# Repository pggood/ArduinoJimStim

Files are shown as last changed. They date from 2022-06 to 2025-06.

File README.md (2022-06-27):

# ArduinoJimStim an Arduino implementation of the JimStim used for megasquirt

A pattern based ignition emulator with 44 common ignition and cam patterns . 

The patterns are in 

wheels_default.h 

Each pattern is a sequence where the first digit is the ignition and cam pulse and the second is the number of degrees it applies for .

The sequence is terminated with 0xff,0, where it loops Back to the beginning.

As it is writing directly to PORTB you could potentially have up to 6 outputs in the pattern.

- 00 is all off
- 01 is ignition on cam off
- 02 is cam on ignition off
- 03 is both cam and ignition on

These patterns can either be for 360 degrees or 720 degrees.

If you are constructing a pattern be careful to add up all the degrees in the second field and make sure it adds up to either 360 or 720

This can be done in a spreadsheet first.

The repository holds the Ardunio source code as well as the Kicad PCB Schematic and gerber files that can be made by people like pcbway, jlcpcb or whoever you preferred PCB maker is. The design is through hole so can be put together by a hobbyist with basic soldering skills.

This is completely open source so do with it as you wish however it is provided on the basis that you use it with your best skill and knowledge and may contain bugs

Wheel Number|DIP Switch  |Wheel Mode                       |Type              |Cam Signal
------------|------------|---------------------------------|------------------|----------  
0           |000000      |Distributor/EDIS|Distributor/EDIS|                  |
1           |000001      |36-1                             |36-1              |X
2           |000010      |60-2                             |60-2              |X
3           |000011      |4-1                              |4-1               |X
4           |000100      |24/2 (Nippondenso)               |24/2 (Nippondenso)|X
5           |000101      |NGC 4 cyl. 36-1+1                |NGC 4 cyl. 36-1+1 |X
6|000110|36-2-2-2|36-2-2-2|X
7|000111|6-1|6-1|X
8|001000|Neon/420A|Neon/420A|X
9|001001|LS1|24+rising/falling (LS1)|X
10|001010|12-1|12-1|X
11|001011|Subaru 6/7|Subaru 6/7|X
12|001100|Trigger return|Trigger return dizzy|
13|001101|Oddfire VR|Oddfire dizzy|
14|001110|Mitsubishi 6G72|Mitsubishi 6G72|X
16|010000|CAS 4/1|4/1 CAS|X
17|010001|4G63|4G63 (Miata)|X
18|010010|Renix 44-2-2|Renix 44-2-2|
19|010011|Twin trigger even|Twin trigger even|X
20|010100|Twin trigger odd|Twin trigger odd|X
21|010101|Suzuki Swift|Suzuki Swift|
22|010110|Suzuki Vitara 2.0|Suzuki Vitara 2.0|
23|010111|Daihatsu 3 cyl|Daihatsu 3 cyl|
24|011000|Daihatsu 4 cyl|Daihatsu 4 cyl|
25|011001|Miata 99-00|Miata 99-00|X
26|011010|Rover 36-1-1|Rover 36-1-1|X
27|011011|Rover 36-1-1-1-1|Rover 36-1-1-1-1|X
28|011100|Rover 36-2-2|Rover 36-2-2|X
29|011101|Honda RC51|Honda RC51|X
30|011110|Chrysler 2.2/2.5|Chrysler 2.2/2.5|X
31|011111|Do not select this|Do not select this|
32|100000|GM 7x native|GM 7x native|
33|100001|32-2 Harley|32-2 Harley|
34|100010|6/1|6/1|X
35|100011|8/1|8/1|X
36|100100|10/1|10/1|X
37|100101|Honda VTR1000 12-3|Honda VTR1000 12-3|
38|100110|IAW Weber-Marelli|IAW Weber-Marelli|X
39|100111|Fiat 1.8 16V|Fiat 1.8 16V|X
40|101000|Mitsubishi 360 tooth CAS (6 cyl)|Mitsubishi 360 tooth CAS (6 cyl)|X
41|101001|Mitsubishi 360 tooth CAS (8 cyl)|Mitsubishi 360 tooth CAS (8 cyl)|X
42|101010|4.0 Jeep 2000|4.0 Jeep 2000|X
43|101011|3.7 Jeep 2002|3.7 Jeep 2002|X
44|101100|NGC 6 cyl. 36-1+1|NGC 6 cyl. 36-1+1|X
45|101101|NGC 8 cyl. 36-1+1|NGC 8 cyl. 36-1+1|X

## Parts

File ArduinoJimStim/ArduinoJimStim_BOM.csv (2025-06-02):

Id | Designator | Package | Quantity | Designation | Supplier and ref
1 | RN1 | R_Array_SIP9 | 1 | R_Network08_US
2 | D2,D8,D4,D5,D1,D6,D11,D10,D9,D7,D12,D3 | LED_D3.0mm_Clear | 12 | LED
3 | J10 | BarrelJack_Horizontal | 1 | Barrel_Jack
4 | R10,R15,R17,R12,R14,R13,R16,R4,R11,R6,R3,R8 | R_Axial_DIN0204_L3.6mm_D1.6mm_P7.62mm_Horizontal | 12 | 330
5 | J4 | PinHeader_1x01_P2.54mm_Vertical | 1 | 2ND Trigger
6 | C1 | C_Radial_D8.0mm_H11.5mm_P3.50mm | 1 | 100n
7 | J3 | PinHeader_1x02_P2.54mm_Vertical | 1 | O2
8 | J8,J7 | PinHeader_1x01_P2.54mm_Vertical | 2 | 12v
9 | D13 | D_A-405_P12.70mm_Horizontal | 1 | D
10 | J5 | DSUB-37_Female_Horizontal_P2.77x2.84mm_EdgePinOffset4.94mm_Housed_MountingHolesOffset7.48mm | 1 | DB37_Male
11 | MAT1,CLT1,RPM1,O2,TPS1 | Potentiometer_Vishay_148-149_Single_Horizontal | 5 | 10K
12 | Q2,Q1 | TO-92_Inline | 2 | 2N3904
13 | R5,R1,R2,R7,R9 | R_Axial_DIN0204_L3.6mm_D1.6mm_P7.62mm_Horizontal | 5 | 1K
14 | J1 | PinHeader_1x03_P2.54mm_Vertical | 1 | TACH
15 | J2 | PinHeader_2x03_P2.54mm_Vertical | 1 | Conn_02x03_Odd_Even
16 | SW1 | MTS-101_SPST | 1 | SW_SPST
17 | A1 | Arduino_Nano | 1 | Arduino_Nano_v3.x
18 | J9 | PinHeader_1x10_P2.54mm_Vertical | 1 | Conn_01x10_Female
19 | SW2 | SW_DIP_SPSTx06_Slide_9.78x17.42mm_W7.62mm_P2.54mm | 1 | SW_DIP_x06
20 | J6 | PinHeader_1x19_P2.54mm_Vertical | 1 | Conn_01x19_Male

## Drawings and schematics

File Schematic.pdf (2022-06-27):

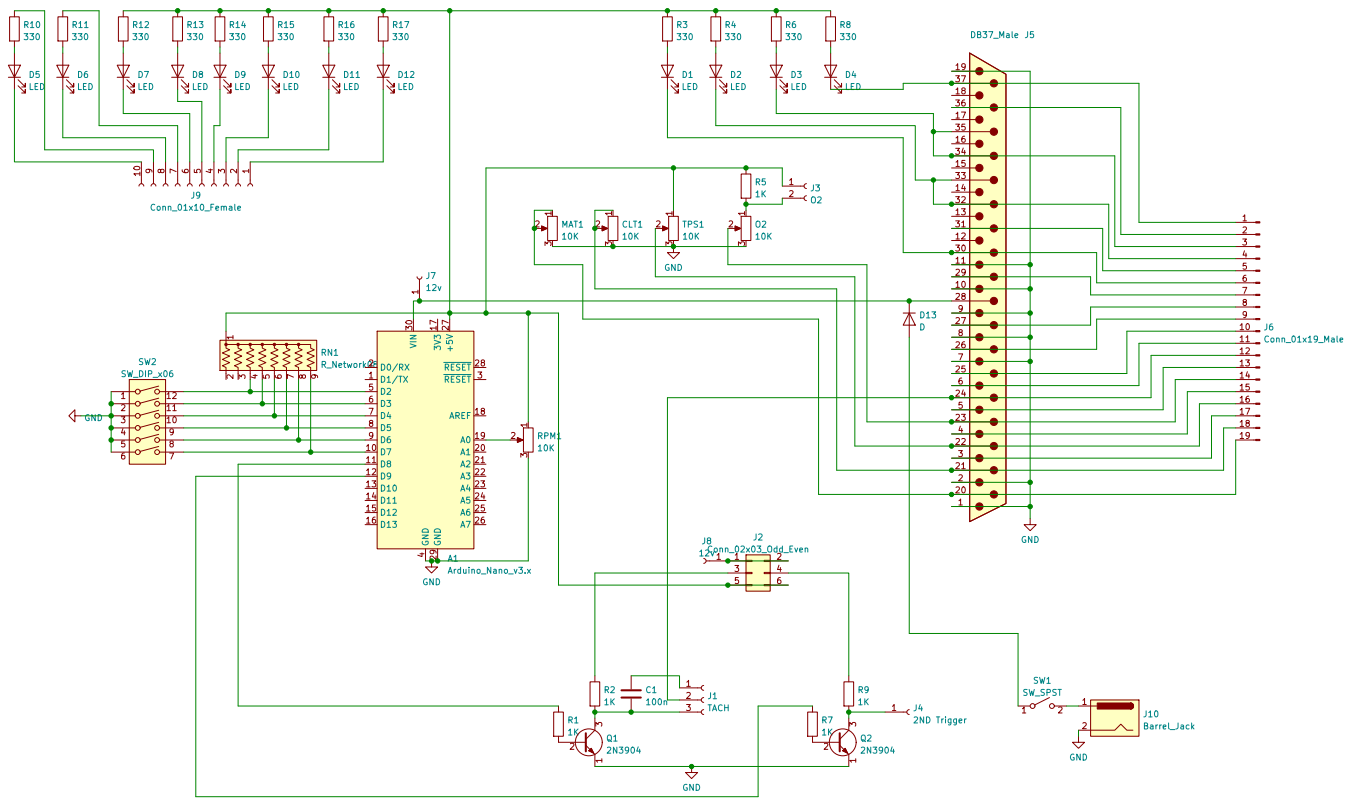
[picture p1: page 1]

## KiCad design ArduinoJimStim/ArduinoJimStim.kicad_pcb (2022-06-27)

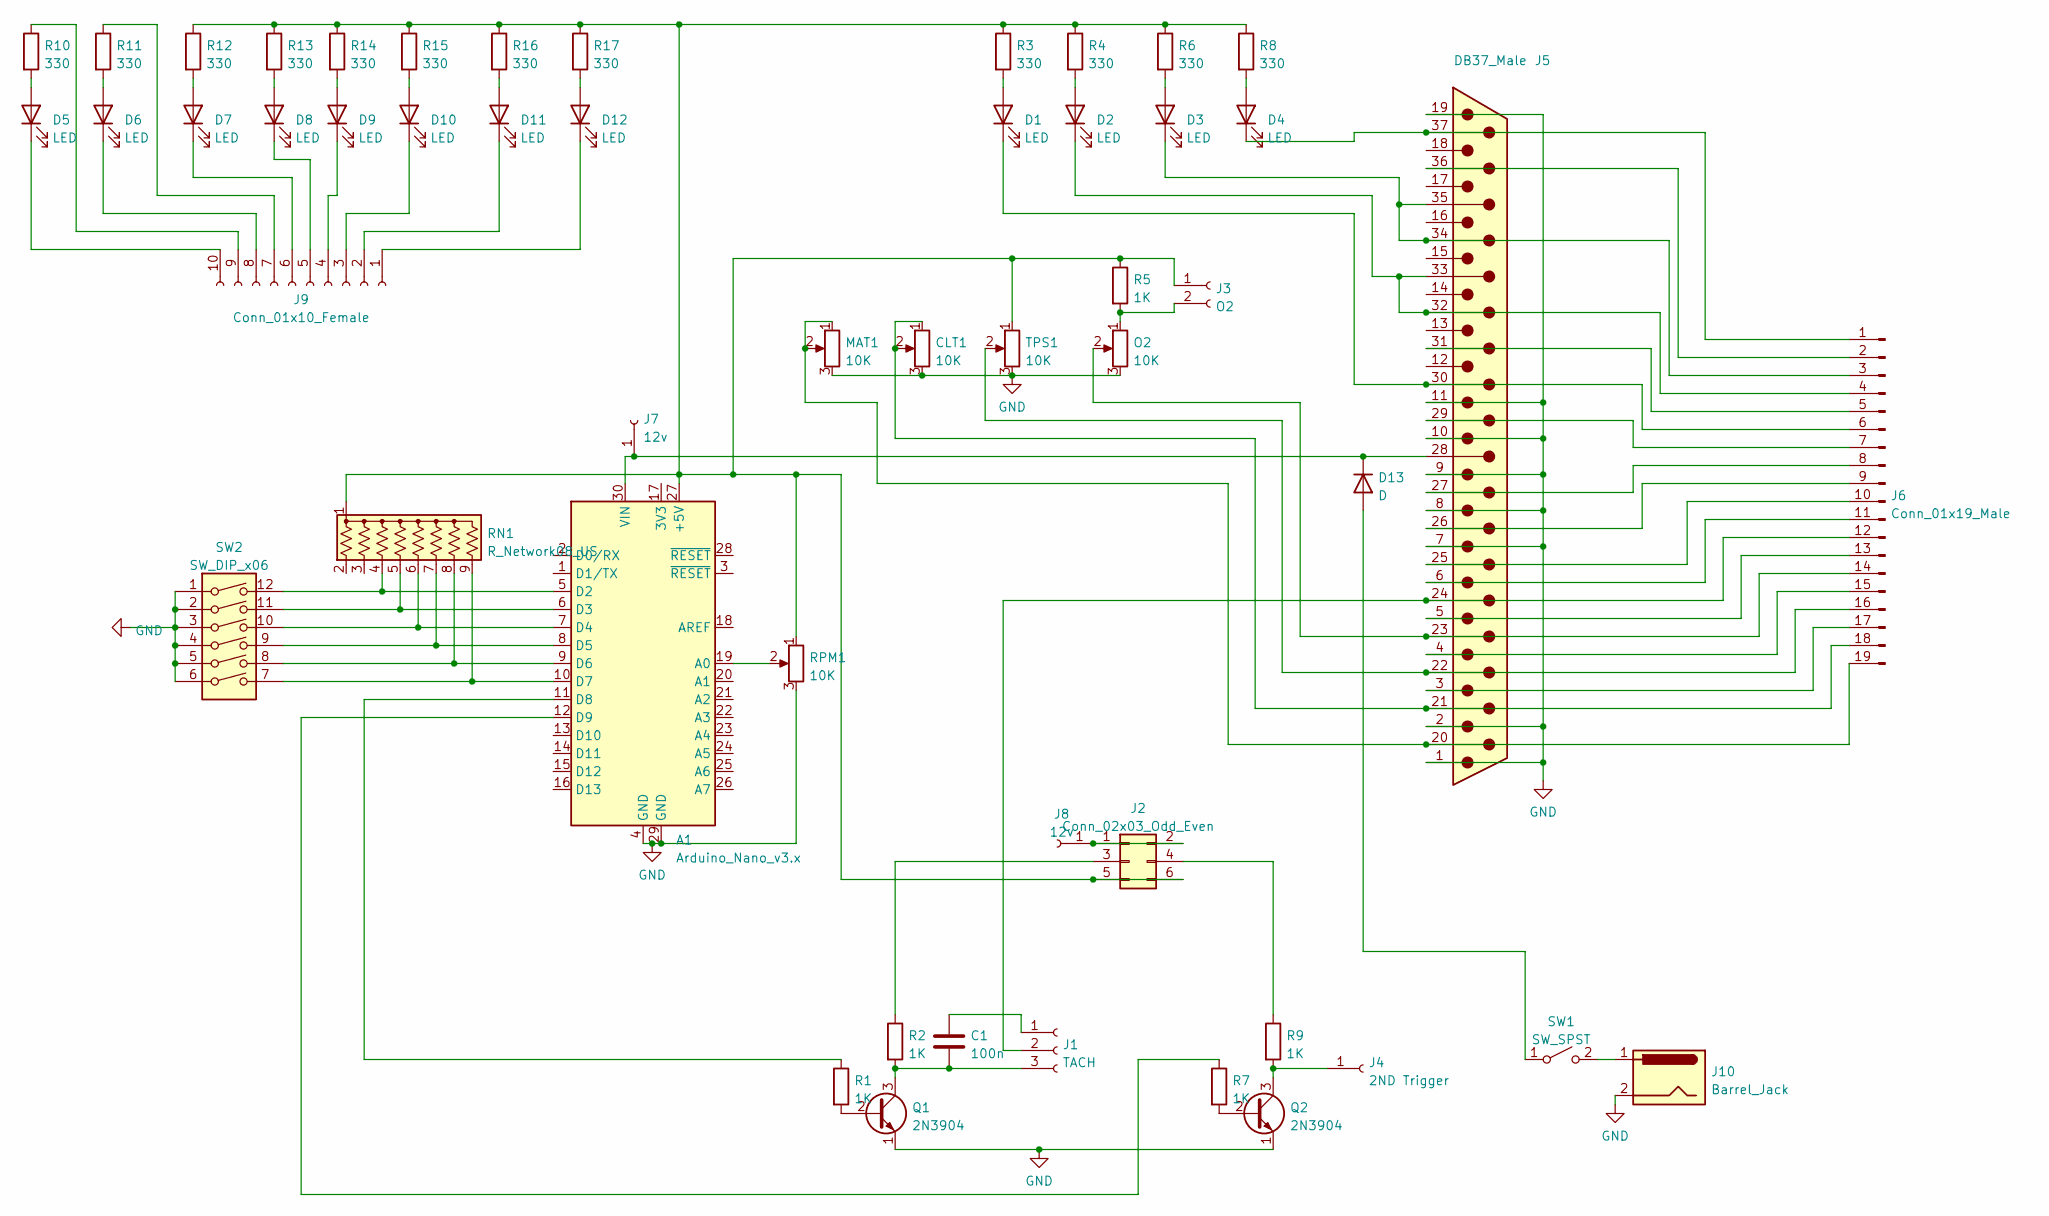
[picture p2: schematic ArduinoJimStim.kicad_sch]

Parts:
A1: Arduino_Nano_v3.x; Arduino_Nano
C1: 100n; C_Radial_D8.0mm_H11.5mm_P3.50mm
CLT1: 10K; Potentiometer_Vishay_148-149_Single_Horizontal
D1, D2, D3, D4, D5, D6, D7, D8, D9, D10, D11, D12: LED; LED_D3.0mm_Clear
D13: D; D_A-405_P12.70mm_Horizontal
J1: TACH; PinHeader_1x03_P2.54mm_Vertical
J2: Conn_02x03_Odd_Even; PinHeader_2x03_P2.54mm_Vertical
J3: O2; PinHeader_1x02_P2.54mm_Vertical
J4: 2ND Trigger; PinHeader_1x01_P2.54mm_Vertical
J5: DB37_Male; DSUB-37_Female_Horizontal_P2.77x2.84mm_EdgePinOffset4.94mm_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
J6: Conn_01x19_Male; PinHeader_1x19_P2.54mm_Vertical
J7, J8: 12v; PinHeader_1x01_P2.54mm_Vertical
J9: Conn_01x10_Female; PinHeader_1x10_P2.54mm_Vertical
J10: Barrel_Jack; BarrelJack_Horizontal
MAT1: 10K; Potentiometer_Vishay_148-149_Single_Horizontal
O2: 10K; Potentiometer_Vishay_148-149_Single_Horizontal
Q1, Q2: 2N3904; TO-92_Inline
R1, R2, R5, R7, R9: 1K; R_Axial_DIN0204_L3.6mm_D1.6mm_P7.62mm_Horizontal
R3, R4, R6, R8, R10, R11, R12, R13, R14, R15, R16, R17: 330; R_Axial_DIN0204_L3.6mm_D1.6mm_P7.62mm_Horizontal
RN1: R_Network08_US; R_Array_SIP9
RPM1: 10K; Potentiometer_Vishay_148-149_Single_Horizontal
SW1: SW_SPST; MTS-101_SPST
SW2: SW_DIP_x06; SW_DIP_SPSTx06_Slide_9.78x17.42mm_W7.62mm_P2.54mm
TPS1: 10K; Potentiometer_Vishay_148-149_Single_Horizontal

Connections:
GND: A1.4 (GND), A1.29 (GND), CLT1.3, J5.1, J5.2, J5.7, J5.8, J5.9, J5.10, J5.11, J5.19, J10.2, MAT1.3, O2.3, Q1.1 (E), Q2.1 (E), RPM1.3, SW2.1, SW2.2, SW2.3, SW2.4, SW2.5, SW2.6, TPS1.3
unnamed: A1.5 (D2), RN1.4 (R3), SW2.12
unnamed: A1.6 (D3), RN1.5 (R4), SW2.11
unnamed: A1.7 (D4), RN1.6 (R5), SW2.10
unnamed: A1.8 (D5), RN1.7 (R6), SW2.9
unnamed: A1.9 (D6), RN1.8 (R7), SW2.8
unnamed: A1.10 (D7), RN1.9 (R8), SW2.7
unnamed: A1.11 (D8), R1.1
unnamed: A1.12 (D9), R7.1
unnamed: A1.19 (A0), RPM1.2
unnamed: A1.27 (+5V), J2.5, J2.6, J3.1, R3.1, R4.1, R5.1, R6.1, R8.1, R12.1, R13.1, R14.1, R15.1, R16.1, R17.1, RN1.1 (common), RPM1.1, TPS1.1
unnamed: A1.30 (VIN), D13.1 (K), J5.28, J7.1
unnamed: C1.1, J1.1
unnamed: C1.2, J1.3, Q1.3 (C), R2.2
unnamed: CLT1.1, CLT1.2, J5.21, J6.18
unnamed: D1.1 (K), J5.30, J6.6
unnamed: D1.2 (A), R3.2
unnamed: D2.1 (K), J5.32, J5.33, J6.4
unnamed: D2.2 (A), R4.2
unnamed: D3.1 (K), J5.34, J5.35, J6.3
unnamed: D3.2 (A), R6.2
unnamed: D4.1 (K), J5.37, J6.1
unnamed: D4.2 (A), R8.2
unnamed: D5.1 (K), J9.10
unnamed: D5.2 (A), R10.2
unnamed: D6.1 (K), J9.8
unnamed: D6.2 (A), R11.2
unnamed: D7.1 (K), J9.6
unnamed: D7.2 (A), R12.2
unnamed: D8.1 (K), J9.5
unnamed: D8.2 (A), R13.2
unnamed: D9.1 (K), J9.4
unnamed: D9.2 (A), R14.2
unnamed: D10.1 (K), J9.3
unnamed: D10.2 (A), R15.2
unnamed: D11.1 (K), J9.2
unnamed: D11.2 (A), R16.2
unnamed: D12.1 (K), J9.1
unnamed: D12.2 (A), R17.2
unnamed: D13.2 (A), SW1.1 (A)
unnamed: J1.2, J5.24, J6.12
unnamed: J2.1, J2.2, J8.1
unnamed: J2.3, R2.1
unnamed: J2.4, R9.1
unnamed: J3.2, O2.1, R5.2
unnamed: J4.1, Q2.3 (C), R9.2
unnamed: J5.3, J6.17
unnamed: J5.4, J6.15
unnamed: J5.5, J6.13
unnamed: J5.6, J6.11
unnamed: J5.20, J6.19, MAT1.1, MAT1.2
unnamed: J5.22, J6.16, TPS1.2
unnamed: J5.23, J6.14, O2.2
unnamed: J5.25, J6.10
unnamed: J5.26, J6.9
unnamed: J5.27, J6.8
unnamed: J5.29, J6.7
unnamed: J5.31, J6.5
unnamed: J5.36, J6.2
unnamed: J9.7, R11.1
unnamed: J9.9, R10.1
unnamed: J10.1, SW1.2 (B)
unnamed: Q1.2 (B), R1.2
unnamed: Q2.2 (B), R7.2

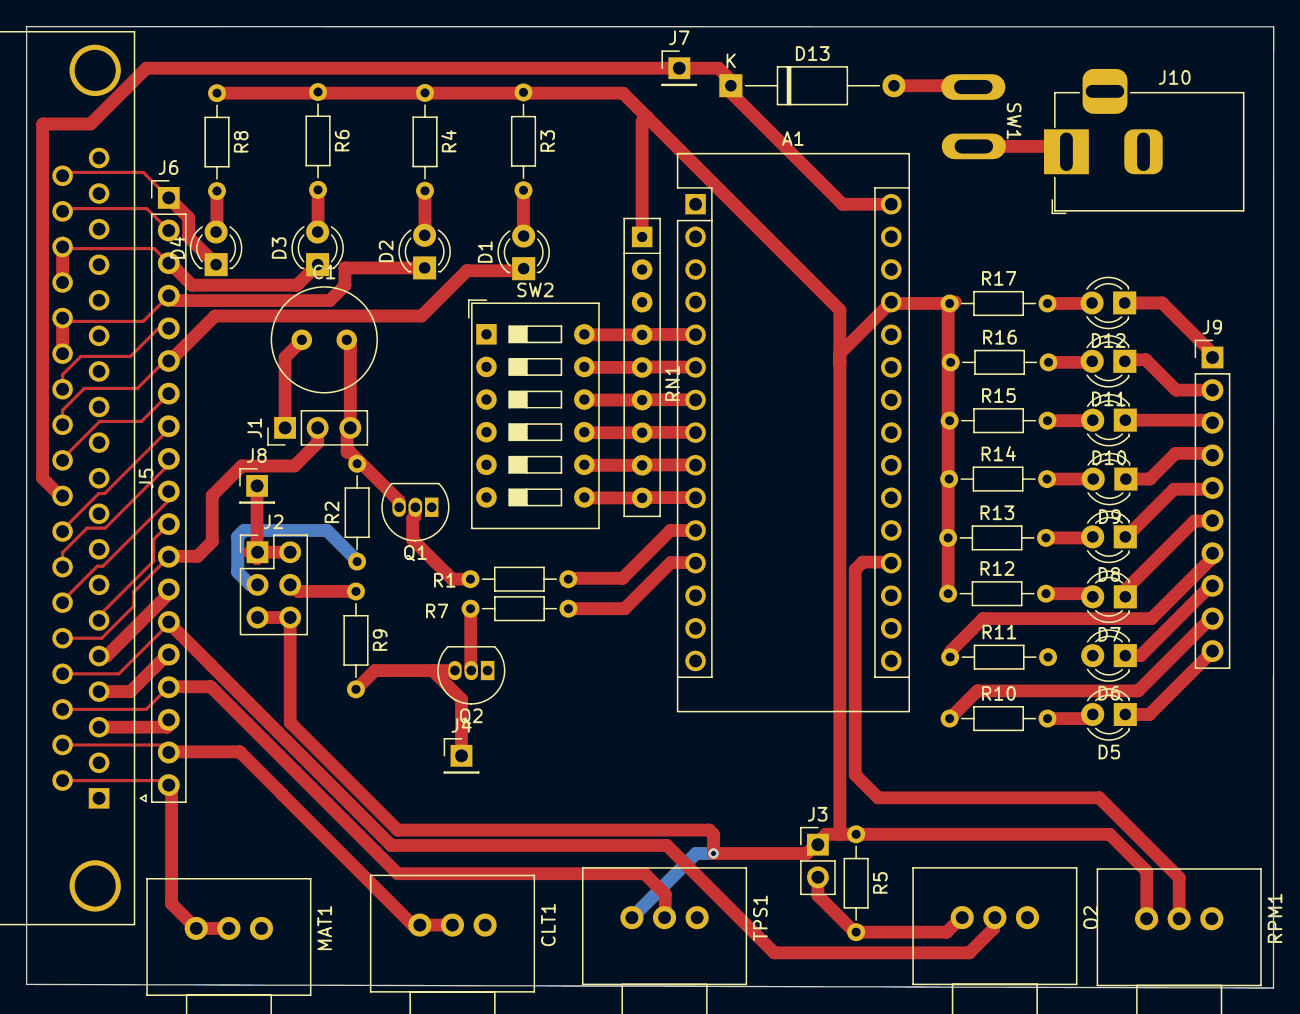
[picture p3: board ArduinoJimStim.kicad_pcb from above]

Board: 2 copper layers, 97.1 x 74.9 mm, 52 parts (0 on the bottom side), 64 nets.

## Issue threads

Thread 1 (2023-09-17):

choose wheel 2 (60-2)

NicoEFI, 2023-09-17:
I wanted to test on a UNO but it doesn't work.

I tested it with an oscilloscope but no signal. I don't use NPN Q1 for the test? maybe this is necessary?
To directly choose wheel 2 (60-2), I comment out all digitalRead and use WheelTypeSet=2; ?
thank you for your help

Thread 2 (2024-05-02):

RPM to 0

sorscode, 2024-05-02:
I really appreciate your code and working on making my own board to use this. The question I have, is I have this working, but I can't get the RPM down to 0. If I use the 36-1 setup, if my potentiometer is at 0, the OCR1A is at 163. I did change the scaling to go from 0 -> 1300 and 0 -> 2600, but that didn't make a change. Also when using this setup, when the potentiometer at 0 the RPM is at the highest and when at 1023, its at its slowest. Thoughts?

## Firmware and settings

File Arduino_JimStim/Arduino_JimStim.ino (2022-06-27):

// analogue pot on anaglog pin0
// this represents routput of 1,000 to 8,000 RPM
#include "wheels_default.h"
#define ledPin 4
volatile uint8_t degree = 0;
uint8_t WheelType=0;
uint8_t WheelTypeSet=0;
uint16_t WheelTypeStart=0;
uint16_t WheelTypeEnd=0;
uint16_t WheelTypeNow=0;
uint8_t WheelValue=0;
uint8_t WheelValueTime=2;
uint8_t WheelValueTimer=0;
uint16_t WheelValueTotal=0;

void setup()
{
  Serial.begin(115200);
  pinMode(2, INPUT);
  pinMode(3, INPUT);
  pinMode(4, INPUT);
  pinMode(5, INPUT);
  pinMode(6, INPUT);
  pinMode(7, INPUT);
  if (digitalRead(2))WheelType=1;
  if (digitalRead(3))WheelType=WheelType+2;
  if (digitalRead(4))WheelType=WheelType+4;
  if (digitalRead(5))WheelType=WheelType+8;
  if (digitalRead(6))WheelType=WheelType+16;
  if (digitalRead(7))WheelType=WheelType+32;
  //WheelTypeSet=0; Manually set wheel type to overide dip switches 
  //digitalWrite(ledPin, LOW);
// initialize timer1
  noInterrupts();           // disable all interrupts
  TCCR1A = 0;
  TCCR1B = 0;
  TCNT1  = 0;

  OCR1A = 2600;            // compare match register 16MHz/256/2Hz
  TCCR1B |= (1 << WGM12);   // CTC mode
  TCCR1B |= (1 << CS10) | (0 << CS11) | (0 << CS12);    // 1 prescaler
  TIMSK1 |= (1 << OCIE1A);  // enable timer compare interrupt
  interrupts();             // enable all interrupts
  for (int i = 0; i < sizeof(WHEEL); i=i+2) {
    //Serial.print(i, DEC);
    //Serial.print(" = ");
    WheelValue = pgm_read_byte_near(WHEEL + i);
    if (WheelValue==255){
      if (WheelTypeSet++<=WheelType){
        WheelTypeStart=WheelTypeEnd+2;
        WheelTypeEnd=i;
      }
    }
    WheelValueTime = pgm_read_byte_near(WHEEL + i+1);
  /*  Serial.print(WheelValue,DEC);
    Serial.print(" , ");
    Serial.print(WheelValueTime,DEC);
    Serial.print(" , ");
    Serial.print(WheelType,DEC);
    Serial.print(" , ");
    Serial.print(WheelTypeStart,DEC);
    Serial.print(" , ");
    Serial.println(WheelTypeEnd,DEC);
    */
  }
  Serial.print(WheelType,DEC);
  Serial.print(" , ");
  Serial.print(WheelTypeStart,DEC);
  Serial.print(" , ");
  Serial.println(WheelTypeEnd,DEC);
  for (int i = WheelTypeStart; i < WheelTypeEnd; i=i+2) {
    WheelValue = pgm_read_byte_near(WHEEL + i);
    WheelValueTime = pgm_read_byte_near(WHEEL + i+1);
    WheelValueTotal = WheelValueTotal+WheelValueTime;
    Serial.print(i/2, DEC);
    Serial.print(" = ");
    Serial.print(WheelValue,DEC);
    Serial.print(" , ");
    Serial.println(WheelValueTime,DEC);
  }
  Serial.println(WheelValueTotal,DEC);
  WheelTypeNow=WheelTypeStart;
}

ISR(TIMER1_COMPA_vect)          // timer compare interrupt service routine
{
 if (WheelValueTimer==WheelValueTime){
  //digitalWrite(ledPin, HIGH);
  WheelValueTimer=0;     
  WheelValue = pgm_read_byte_near(WHEEL + WheelTypeNow); 
  WheelValueTime = pgm_read_byte_near(WHEEL + WheelTypeNow+1);
  PORTB=WheelValue;
  WheelTypeNow=WheelTypeNow+2; 
  if (WheelTypeNow>=WheelTypeEnd){
    //digitalWrite(ledPin, HIGH);
    WheelTypeNow=WheelTypeStart;     
  }   
 }
 WheelValueTimer++;
 //digitalWrite(ledPin, LOW);
}

void loop()
{
  // your program here...
  //OCR1A = map(analogRead(A0), 0, 1023, 1667, 13333);
  if (WheelValueTotal==360){
    OCR1A = map(analogRead(A0), 0, 1023, 325, 2600);
  }else{
    OCR1A = map(analogRead(A0), 0, 1023, 163, 1300);
  }
  delay(250);
}

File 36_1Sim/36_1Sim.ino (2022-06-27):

// analogue pot on anaglog pin0
// this represents routput of 1,000 to 8,000 RPM
#define ledPin 10
volatile int toothCount = 0;
volatile int missingTick = 0;

void setup()
{
  Serial.begin(115200);
  pinMode(ledPin, OUTPUT);
  digitalWrite(ledPin, LOW);
// initialize timer1
  noInterrupts();           // disable all interrupts
  TCCR1A = 0;
  TCCR1B = 0;
  TCNT1  = 0;

  OCR1A = 13333;            // compare match register 16MHz/256/2Hz
  TCCR1B |= (1 << WGM12);   // CTC mode
  TCCR1B |= (1 << CS10) | (0 << CS11) | (0 << CS12);    // 1 prescaler
  TIMSK1 |= (1 << OCIE1A);  // enable timer compare interrupt
  interrupts();             // enable all interrupts
}

ISR(TIMER1_COMPA_vect)          // timer compare interrupt service routine
{
  if (toothCount <= 69) // 0 thru 69 is 70 toggles or 35 pulses per rev.
  {
    digitalWrite(ledPin, digitalRead(ledPin) ^ 1);   // toggle LED pin
    toothCount++;
  }
  else {
    missingTick++;  // 2 toggles - 1 missing pulse per revolution
    if (missingTick == 2) {
      toothCount = 0;
      missingTick = 0;
    }
  }
}

void loop()
{
  // your program here...
  OCR1A = map(analogRead(A0), 0, 1023, 1667, 13333);
  delay(250);
}

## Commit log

2022-06-27 36 missing tooth Arduino ignition emulator
    A simple 36 tooth ignition emulator for Arduino using a pot to vary the RPM
    [36_1Sim.ino]
2022-06-27 JimStim for Arduino
    A pattern based ignition emulator with 44 common ignition and cam patterns . The patterns are in wheels_default.h
    Each pattern is a sequence where the first digit is the ignition and cam pulse and the sequence is terminated with 0xff,0, where it loops Back to the beginning.
    As it is writing directly to PORTB you could potentially have up to 6 outputs in the pattern.
    00 is all off
    01 is ignition on cam off
    02 is cam on ignition off
    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
    [ArduinoJimStim-B_Cu.gbr, ArduinoJimStim-B_Mask.gbr, ArduinoJimStim-B_Paste.gbr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]
2025-06-02 Basic BOM
    [ArduinoJimStim_BOM.csv]
